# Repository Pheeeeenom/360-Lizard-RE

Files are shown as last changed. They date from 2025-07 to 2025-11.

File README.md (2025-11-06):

<div align="center">
  Lizard Logo
</div>

<h1 align="center">The Ultimate Flashing Tool</h1>

<p align="center">
  A "modern" clone to the 360 Lizard. 
</p>

# Why bother cloning this?

Mostly for preservations sake, but it really annoyed me having to deal with Windows 10/11 and driver issues, old LTU pcb's getting stuck on "writing .", JungleFlasher using very suspicious remote execution dll's (I'll be going into the software side later in the docs), the clutter of having to having cables all over the place/pc needing to be open to get access to a SATA plug. List goes on.

# Clone features

* Modernize with USB-C
* Replace the old 27 pin out of production 0.96 SPI 1306 screen with a 30 pin equivalent.
* Removeable screen so it's repairable with little effort

# Original features

* Hardware Flasher with Unlock, Read, Write, Erase, Key Retrieval
* Support all Xbox 360 Drives, Samsung, Hitachi, Benq, Liteon, and Slim Liteon. (yes it also unlock and read keys on the latest 0225)
* Built in support for many PC DVD Sata Drives too
* Support Onboard AES 128 Key Verification
* Several Modes of Operation: Use it with your PC or as stand alone
* Micro SD Card Slot for file storage
* Friendly Navigation Menu with simplified button count
* Multilingual Menu
* Free PC companion Software

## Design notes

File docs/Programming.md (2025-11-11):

# Programming / Bring up 
There's 3 total steps needed to be taken to prepare a blank board. Ideally in this order:
* Program the FTDI [.xml](https://raw.githubusercontent.com/Pheeeeenom/360-Lizard-RE/refs/heads/main/sw/FTDI/internal%20EEPROM_PD_true.xml)
* Program the PIC18F87J11 with the [.hex](https://raw.githubusercontent.com/Pheeeeenom/360-Lizard-RE/refs/heads/main/sw/MCU/lizard_v1.34_last_official_fw.hex)
* Program the SPI chip [.bin](https://github.com/Pheeeeenom/360-Lizard-RE/raw/refs/heads/main/sw/SPI/spi_v1.34_last_official_fw.bin)

# FTDI

Use FT_Prog to apply the .xml inside sw/FTDI/.

# PIC18F87J11

Use a [PICKIT 3](https://amazon.com/dp/B07PHPBP3Y) and use the [standalone programmer](https://ww1.microchip.com/downloads/en/DeviceDoc/PICkit_3_Programmer_1_0_Setup_A.zip)

<div align="center">
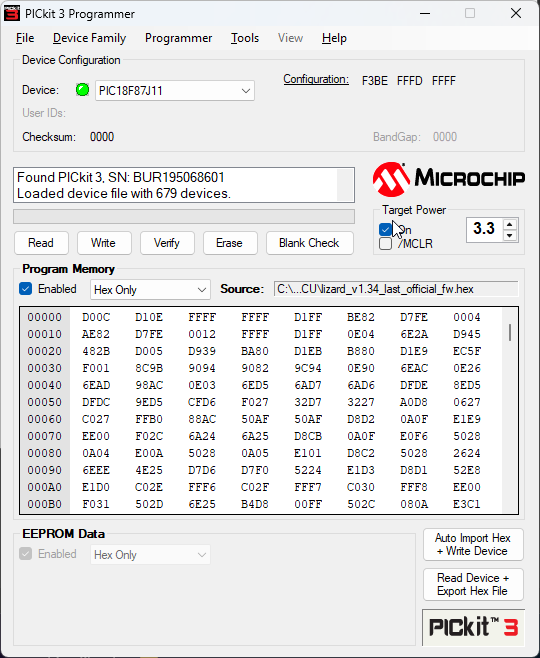
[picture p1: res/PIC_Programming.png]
PIC Settings
  
</div>

<p align="center">
Select the appropriate PIC from the device drop down then select Target Power On checkbox (be sure you do **NOT** select /MCLR). Lastly, select the .hex and click the write button.
</p>

# SPI Chip

<div align="center">
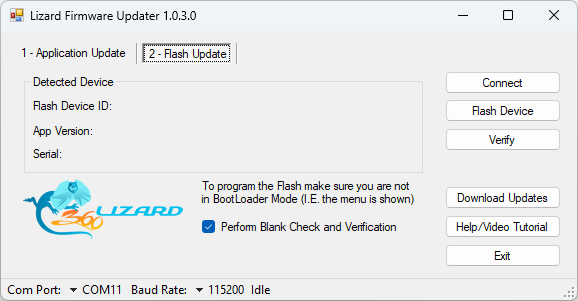
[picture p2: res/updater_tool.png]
updater settings
  
</div>

Use the [updater tool](https://github.com/Pheeeeenom/360-Lizard-RE/raw/refs/heads/main/sw/LizardFwUpdater_work_deob.exe) and click on "2 - Flash Update" then click connect and once it connects click Flash Device and select the .bin just wait.

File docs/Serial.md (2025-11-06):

# Retaining Serial Number
Get your serial number prior to doing anything by connecting your existing lizard to the PC and opening the toolbox.
# Intel HEX Checksum Calculation

## Steps
1. **Ignore** the starting colon (`:`).  
2. **Sum** all bytes in the record:
   - Byte count  
   - Address (2 bytes)  
   - Record type  
   - Data bytes  
3. **Keep only** the least significant byte of the sum (sum mod 256).  
4. **Compute the two’s complement**:
5. **Append** the checksum as the last byte.

## Example

Record without checksum: 
:1003F000B13AECEB8DCB4B3C93C79ED3398739A5

---

## Step 1: Split the record

| Field | Bytes | Description |
|---|---|---|
| Byte count | `10` | 16 data bytes |
| Address | `03 F0` | Start address 0x03F0 |
| Record type | `00` | Data record |
| Serial | `B1 3A EC EB 8D CB 4B 3C 93 C7 9E D3 39 87 39 A5` | 16 bytes |

---

## Step 2: Add all bytes (except the colon and checksum)

Let’s add step by step (hex math, keeping only 8-bit sum each time):

| Operation | Sum (Hex) |
|---|---|
| 10 + 03 | 13 |
| 13 + F0 | 103 → 03 |
| 03 + 00 | 03 |
| 03 + B1 | B4 |
| B4 + 3A | EE |
| EE + EC | 1DA → DA |
| DA + EB | 1C5 → C5 |
| C5 + 8D | 152 → 52 |
| 52 + CB | 11D → 1D |
| 1D + 4B | 68 |
| 68 + 3C | A4 |
| A4 + 93 | 137 → 37 |
| 37 + C7 | FE |
| FE + 9E | 19C → 9C |
| 9C + D3 | 16F → 6F |
| 6F + 39 | A8 |
| A8 + 87 | 12F → 2F |
| 2F + 39 | 68 |
| 68 + A5 | 10D → **0D** |

Final sum (mod 256) = **0x0D**

---

## Step 3: Take the two’s complement

0x100 - 0x0D = 0xF3

## Step 4: Append the checksum

Final Intel HEX record: :1003F000B13AECEB8DCB4B3C93C79ED3398739A5F3

## Step 5: Insert this at the appropriate line in the correct location in the hex

You can ctrl+f to find ":1003F000F1C70B8FBAF25C6CF312CC823655D6D1B2" which is the serial + checksum in the latest 1.34 hex.

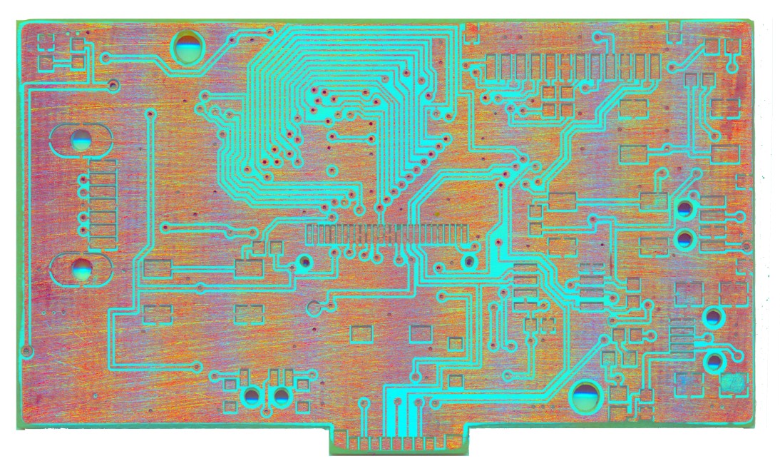
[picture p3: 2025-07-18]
board scans/top.jpg

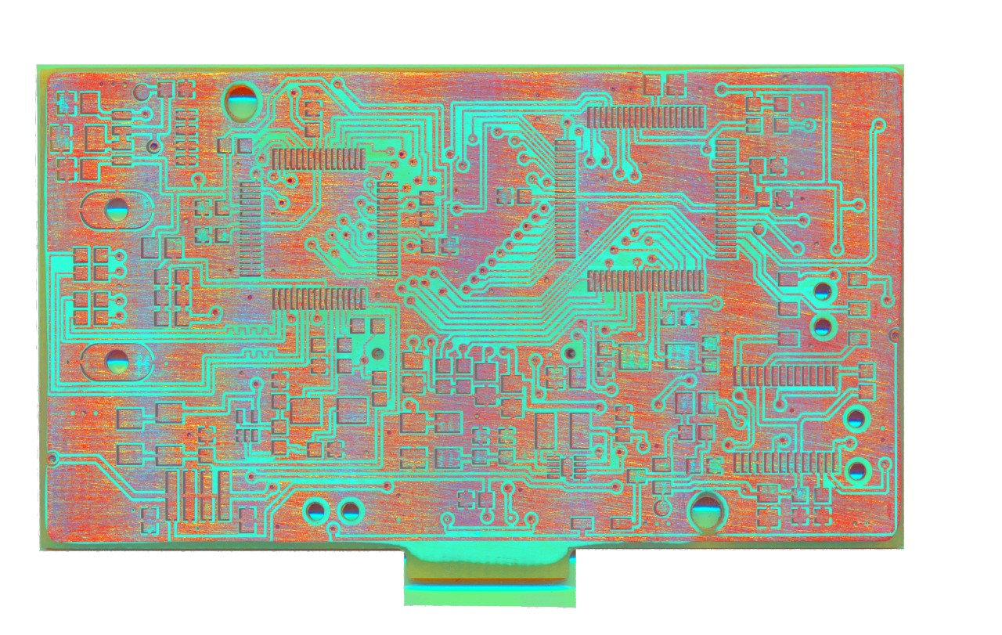
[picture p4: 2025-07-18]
board scans/bottom.jpg

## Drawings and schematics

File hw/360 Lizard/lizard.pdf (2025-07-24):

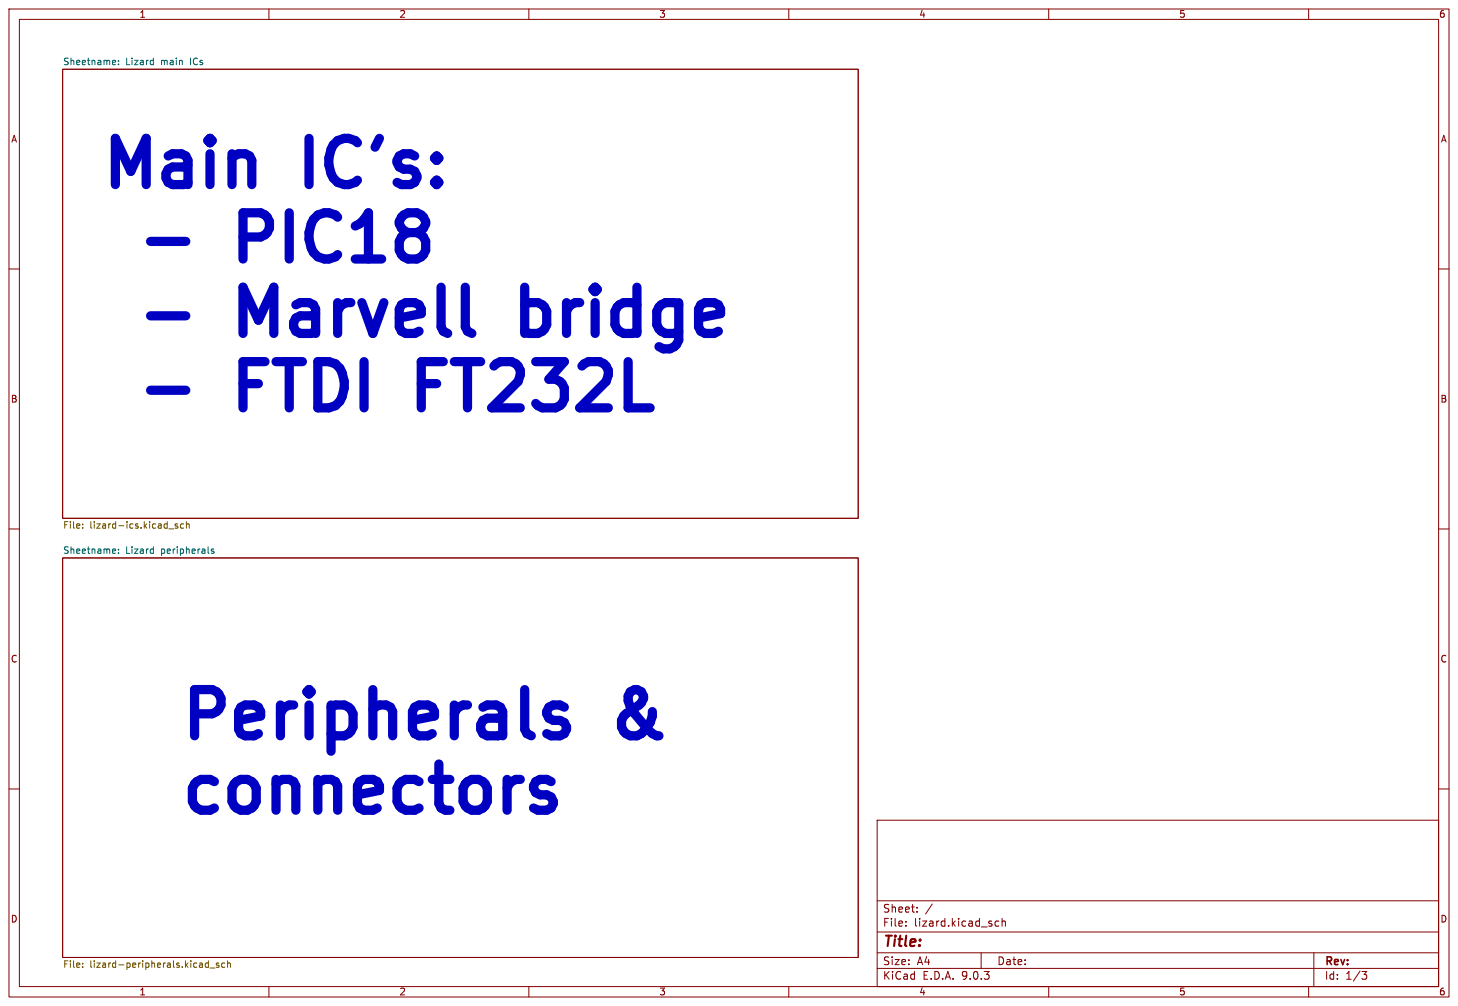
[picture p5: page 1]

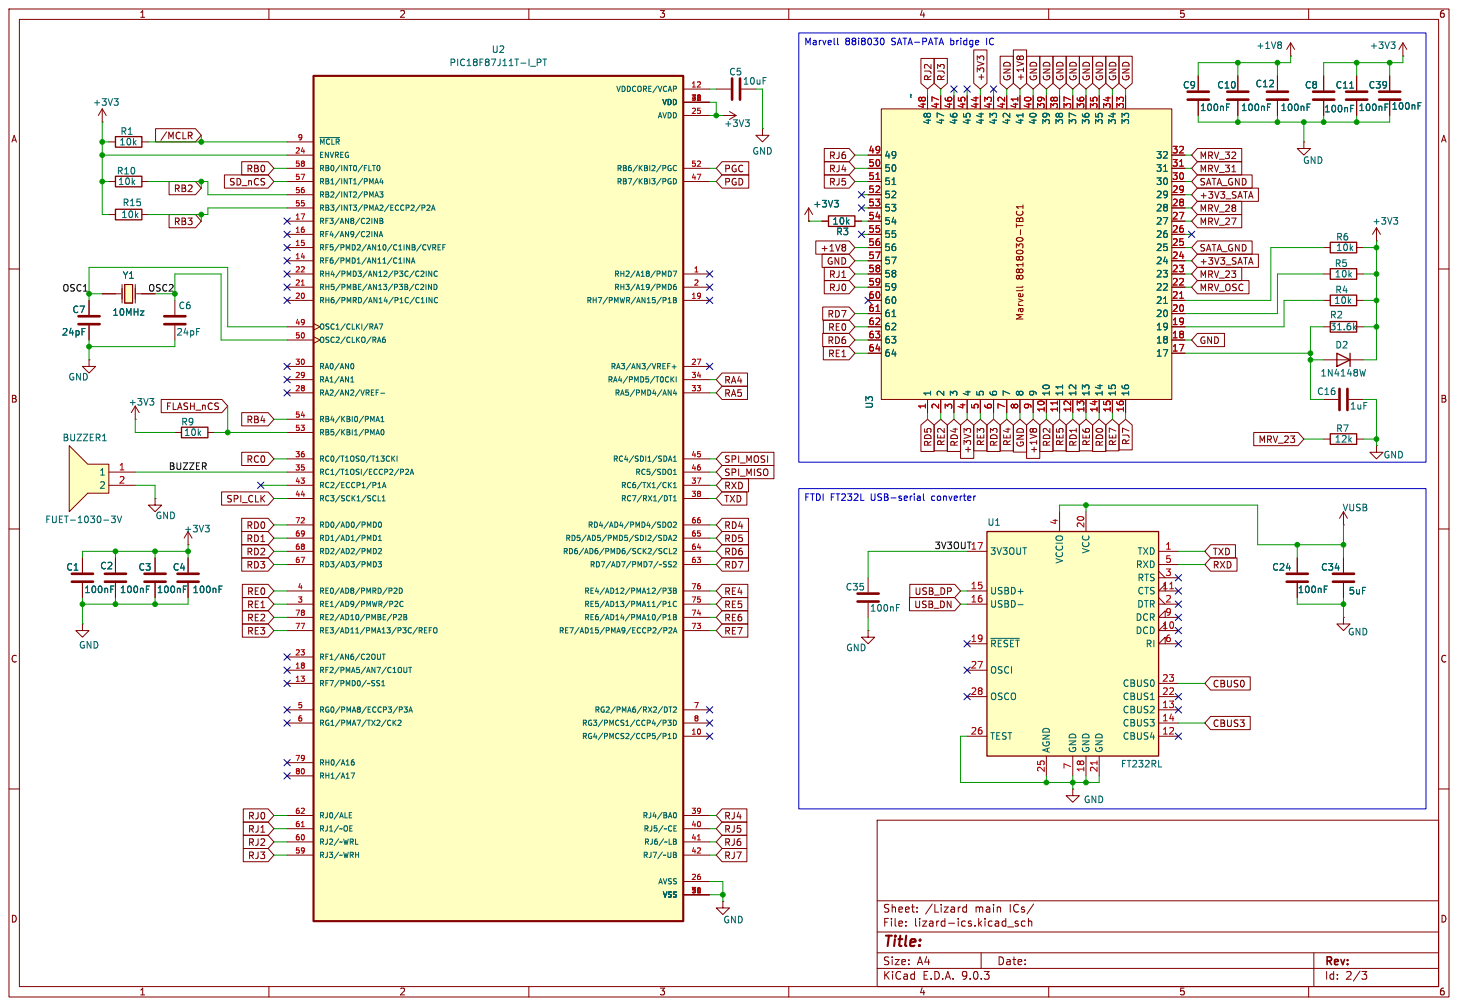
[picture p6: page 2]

7 VCC 20 GND 18 GND 21 TXD 1 RXD 5 RTS 3 CTS 11 DTR 2 DCR 9 DCD 10 RI 6 CBUS0 23 CBUS1 22 CBUS2 13 CBUS3 14 CBUS4 12 U1 FT232RL GND GND

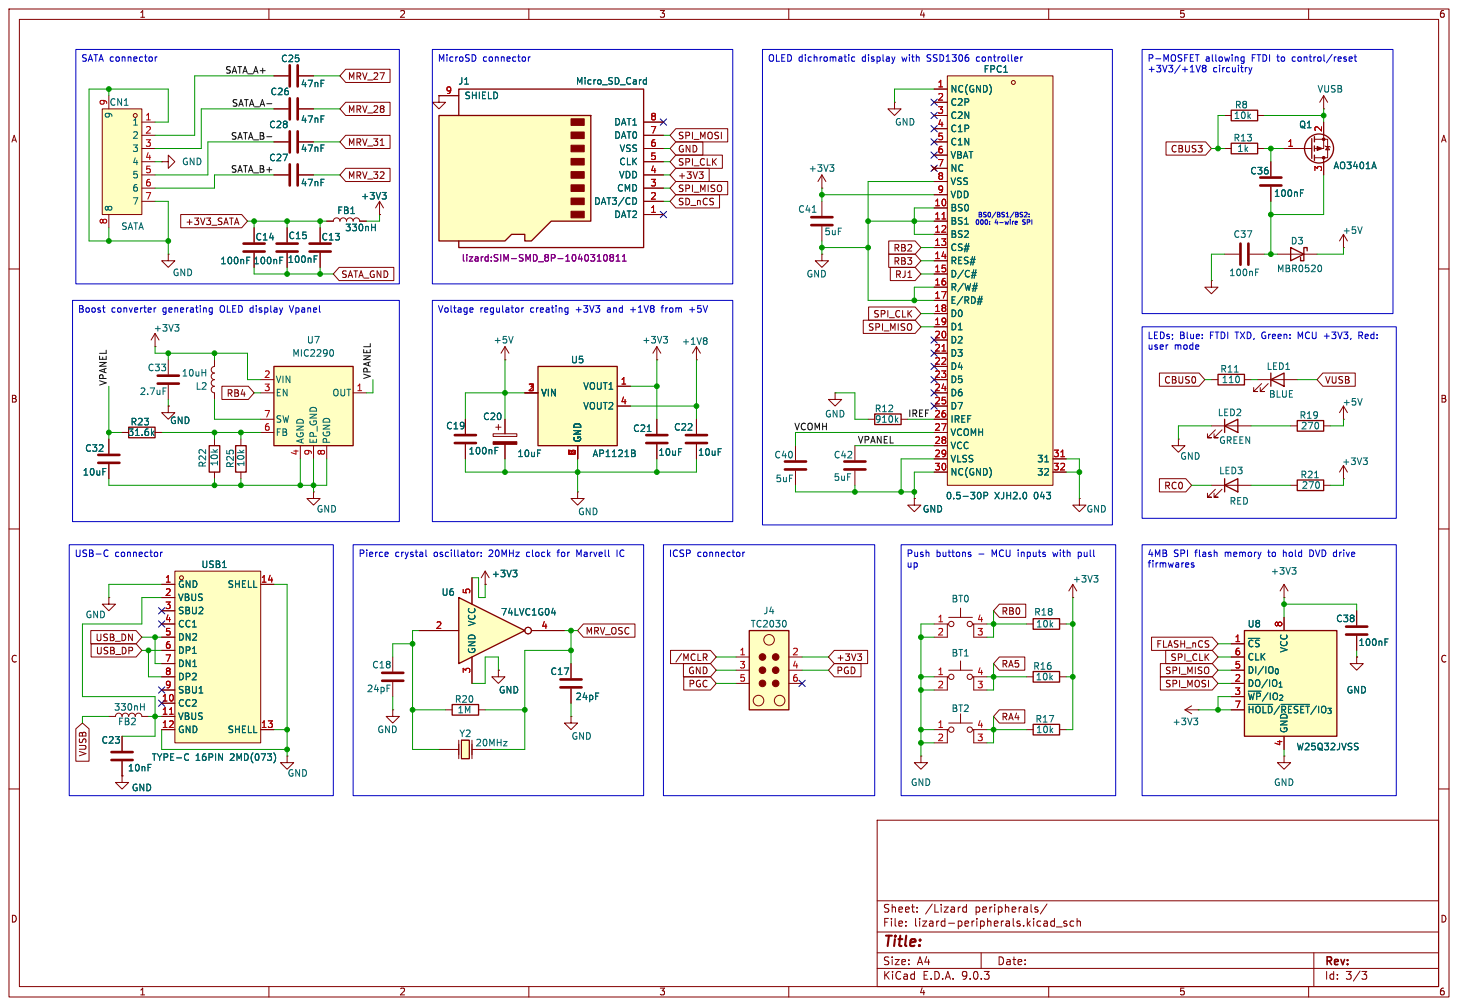
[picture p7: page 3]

4MB SPI flash memory to hold DVD drive
firmwares

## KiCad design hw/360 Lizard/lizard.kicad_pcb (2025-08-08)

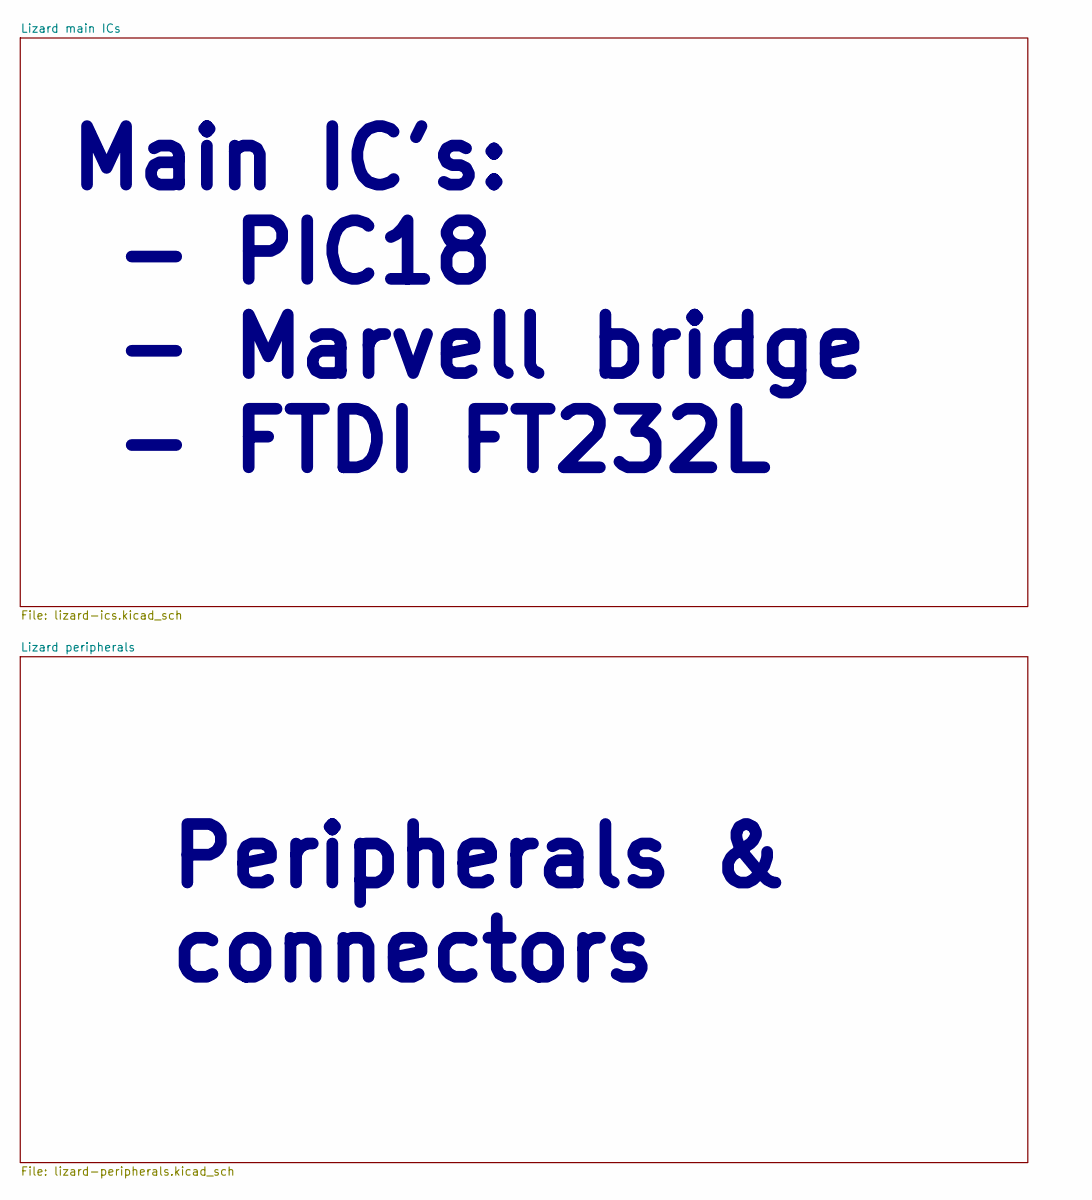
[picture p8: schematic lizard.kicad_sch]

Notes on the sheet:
Peripherals & connectors
Main IC's: - PIC18 - Marvell bridge - FTDI FT232L

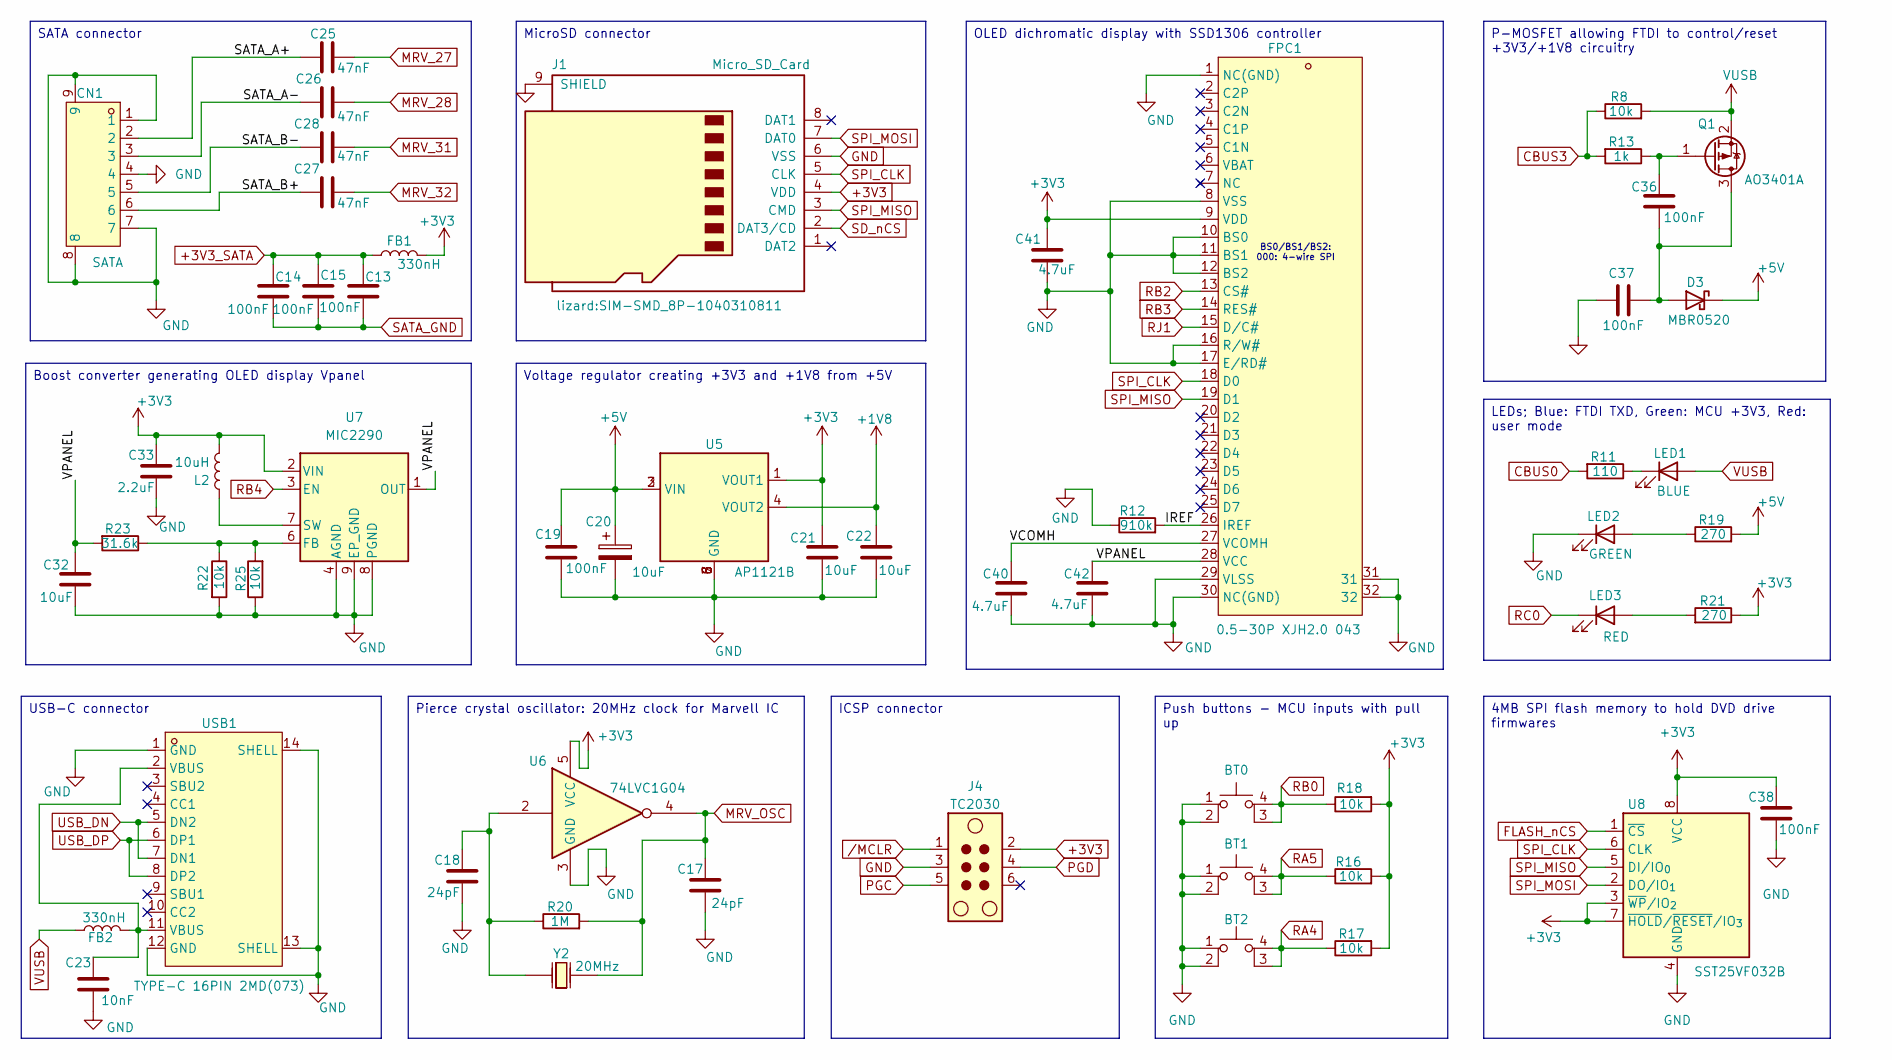
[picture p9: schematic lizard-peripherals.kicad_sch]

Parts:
BT0, BT1, BT2: SW_Push; KEY-SMD_4P-L6.0-W6.0-P4.50-LS9.0
C13, C14, C15, C19, C36, C37, C38: 100nF; C_0603_1608Metric
C17, C18: 24pF; C_0603_1608Metric
C20, C32: 10uF; C_1206_3216Metric
C21, C22: 10uF; C_0805_2012Metric
C23: 10nF; C_0603_1608Metric
C25, C26, C27, C28: 47nF; C_0603_1608Metric
C33: 2.2uF; C_0805_2012Metric
C40, C41, C42: 4.7uF; C_0805_2012Metric
CN1: SATA; CONN-SMD_SATA-401-M07S1BY-A; LCSC Part C7500835
D3: MBR0520; D_SOD-123
FB1: 330nH; L_0805_2012Metric
FB2: 330nH; L_0805_2012Metric_Pad1.15x1.40mm_HandSolder
FPC1: 0.5-30P XJH2.0 043; FPC-SMD_30P-P0.50_0.5-30P-XJH2.0-043; LCSC Part C5373440
J1: Micro_SD_Card; SIM-SMD_8P-1040310811
J4: TC2030; Tag-Connect_TC2030-IDC-NL_2x03_P1.27mm_Vertical
L2: 10uH; L_Wurth_WE-LQSH-3012
LED1: BLUE; LED_0805_2012Metric_Pad1.15x1.40mm_HandSolder
LED2: GREEN; LED_0805_2012Metric_Pad1.15x1.40mm_HandSolder
LED3: RED; LED_0805_2012Metric_Pad1.15x1.40mm_HandSolder
Q1: AO3401A; SOT-23
R8, R16, R17, R18, R22, R25: 10k; R_0603_1608Metric
R11: 110; R_0603_1608Metric
R12: 910k; R_0805_2012Metric
R13: 1k; R_0805_2012Metric
R19, R21: 270; R_0603_1608Metric
R20: 1M; R_0603_1608Metric
R23: 31.6k; R_1206_3216Metric
U5: AP1121B; TSSOP-8_3x3mm_P0.65mm
U6: 74LVC1G04; SOT-353_SC-70-5
U7: MIC2290; Micrel_MLF-8-1EP_2x2mm_P0.5mm_EP0.8x1.3mm_ThermalVias; LCSC Part # C144214
U8: SST25VF032B; SOIC-8_5.3x5.3mm_P1.27mm
USB1: TYPE-C 16PIN 2MD(073); USB-C-SMD_TYPE-C-6PIN-2MD-073; LCSC Part C2765186
Y2: 20MHz; OSC-SMD_L5.0-W3.2; LCSC Part C362485

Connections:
+1V8: C22.2, U5.4 (VOUT2); also elsewhere on the board
+3V3: C21.2, C33.1, C38.1, C41.2, FB1.1, FPC1.9 (VDD), J1.4 (VDD), J4.2, L2.2, R16.2, R17.2, R18.2, R21.1, U5.1 (VOUT1), U6.5 (VCC), U7.2 (VIN), U8.3 (~WP/IO_{2}), U8.7 (~HOLD/~RESET/IO_{3}), U8.8 (VCC); also elsewhere on the board
+3V3_SATA: C13.1, C14.1, C15.1, FB1.2; also elsewhere on the board
+5V: C19.1, C20.1, D3.1 (K), R19.2, U5.2 (VIN), U5.3 (VIN)
/Lizard peripherals/IREF: FPC1.26 (IREF), R12.2
/Lizard peripherals/SATA_A+: C25.2, CN1.2
/Lizard peripherals/SATA_A-: C26.2, CN1.3
/Lizard peripherals/SATA_B+: C27.2, CN1.6
/Lizard peripherals/SATA_B-: C28.2, CN1.5
/Lizard peripherals/VCOMH: C40.2, FPC1.27 (VCOMH)
/Lizard peripherals/VPANEL: C32.2, C42.2, FPC1.28 (VCC), R23.2, U7.1 (OUT)
CBUS0: R11.2; also elsewhere on the board
CBUS3: R8.1, R13.2; also elsewhere on the board
FLASH_nCS: U8.1 (~CS); also elsewhere on the board
GND: BT0.1, BT0.2, BT1.1, BT1.2, BT2.1, BT2.2, C17.2, C18.2, C19.2, C20.2, C21.1, C22.1, C23.1, C32.1, C33.2, C37.1, C38.2, C40.1, C41.1, C42.1, CN1.1, CN1.4, CN1.7, CN1.8, CN1.9, FPC1.1 (NC(GND)), FPC1.8 (VSS), FPC1.10 (BS0), FPC1.11 (BS1), FPC1.12 (BS2), FPC1.16 (R/W#), FPC1.17 (E/RD#), FPC1.29 (VLSS), FPC1.30 (NC(GND)), FPC1.31, FPC1.32, J1.6 (VSS), J1.9 (SHIELD), J4.3, LED2.1 (K), R12.1, R22.2, R25.1, U5.5 (GND), U5.6 (GND), U5.7 (GND), U5.8 (GND), U5.9 (GND), U6.3 (GND), U7.4 (AGND), U7.8 (PGND), U7.9 (EP_GND), U8.4 (GND), USB1.1 (GND), USB1.12 (GND), USB1.13 (SHELL), USB1.14 (SHELL); also elsewhere on the board
MRV_27: C25.1; also elsewhere on the board
MRV_28: C26.1; also elsewhere on the board
MRV_31: C28.1; also elsewhere on the board
MRV_32: C27.1; also elsewhere on the board
MRV_OSC: C17.1, R20.2, U6.4, Y2.1 (OSC1); also elsewhere on the board
unnamed: C23.2, FB2.1, USB1.2 (VBUS), USB1.11 (VBUS)
unnamed: C36.2, C37.2, D3.2 (A), Q1.3 (D)
unnamed: LED1.1 (K), R11.1
unnamed: LED2.2 (A), R19.1
unnamed: LED3.2 (A), R21.2
unnamed: C36.1, Q1.1 (G), R13.1
unnamed: R22.1, R23.1, R25.2, U7.6 (FB)
unnamed: L2.1, U7.7 (SW)
unnamed: C18.1, R20.1, U6.2, Y2.2 (OSC2)
PGC: J4.5; also elsewhere on the board
PGD: J4.4; also elsewhere on the board
RA4: BT2.3 (K), BT2.4 (A), R17.1; also elsewhere on the board
RA5: BT1.3 (K), BT1.4 (A), R16.1; also elsewhere on the board
RB0: BT0.3 (K), BT0.4 (A), R18.1; also elsewhere on the board
RB2: FPC1.13 (CS#); also elsewhere on the board
RB3: FPC1.14 (RES#); also elsewhere on the board
RB4: U7.3 (EN); also elsewhere on the board
RC0: LED3.1 (K); also elsewhere on the board
RJ1: FPC1.15 (D/C#); also elsewhere on the board
SATA_GND: C13.2, C14.2, C15.2; also elsewhere on the board
SD_nCS: J1.2 (DAT3/CD); also elsewhere on the board
SPI_CLK: FPC1.18 (D0), J1.5 (CLK), U8.6 (CLK); also elsewhere on the board
SPI_MISO: FPC1.19 (D1), J1.3 (CMD), U8.5 (DI/IO_{0}); also elsewhere on the board
SPI_MOSI: J1.7 (DAT0), U8.2 (DO/IO_{1}); also elsewhere on the board
USB_DN: USB1.5 (DN2), USB1.7 (DN1); also elsewhere on the board
USB_DP: USB1.6 (DP1), USB1.8 (DP2); also elsewhere on the board
VUSB: FB2.2, LED1.2 (A), Q1.2 (S), R8.2; also elsewhere on the board
/MCLR: J4.1; also elsewhere on the board

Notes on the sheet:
BS0/BS1/BS2: 000: 4-wire SPI
Boost converter generating OLED display Vpanel
4MB SPI flash memory to hold DVD drive firmwares
Voltage regulator creating +3V3 and +1V8 from +5V
Pierce crystal oscillator: 20MHz clock for Marvell IC
USB-C connector
SATA connector
OLED dichromatic display with SSD1306 controller
Push buttons - MCU inputs with pull up
MicroSD connector
P-MOSFET allowing FTDI to control/reset +3V3/+1V8 circuitry
LEDs; Blue: FTDI TXD, Green: MCU +3V3, Red: user mode
ICSP connector

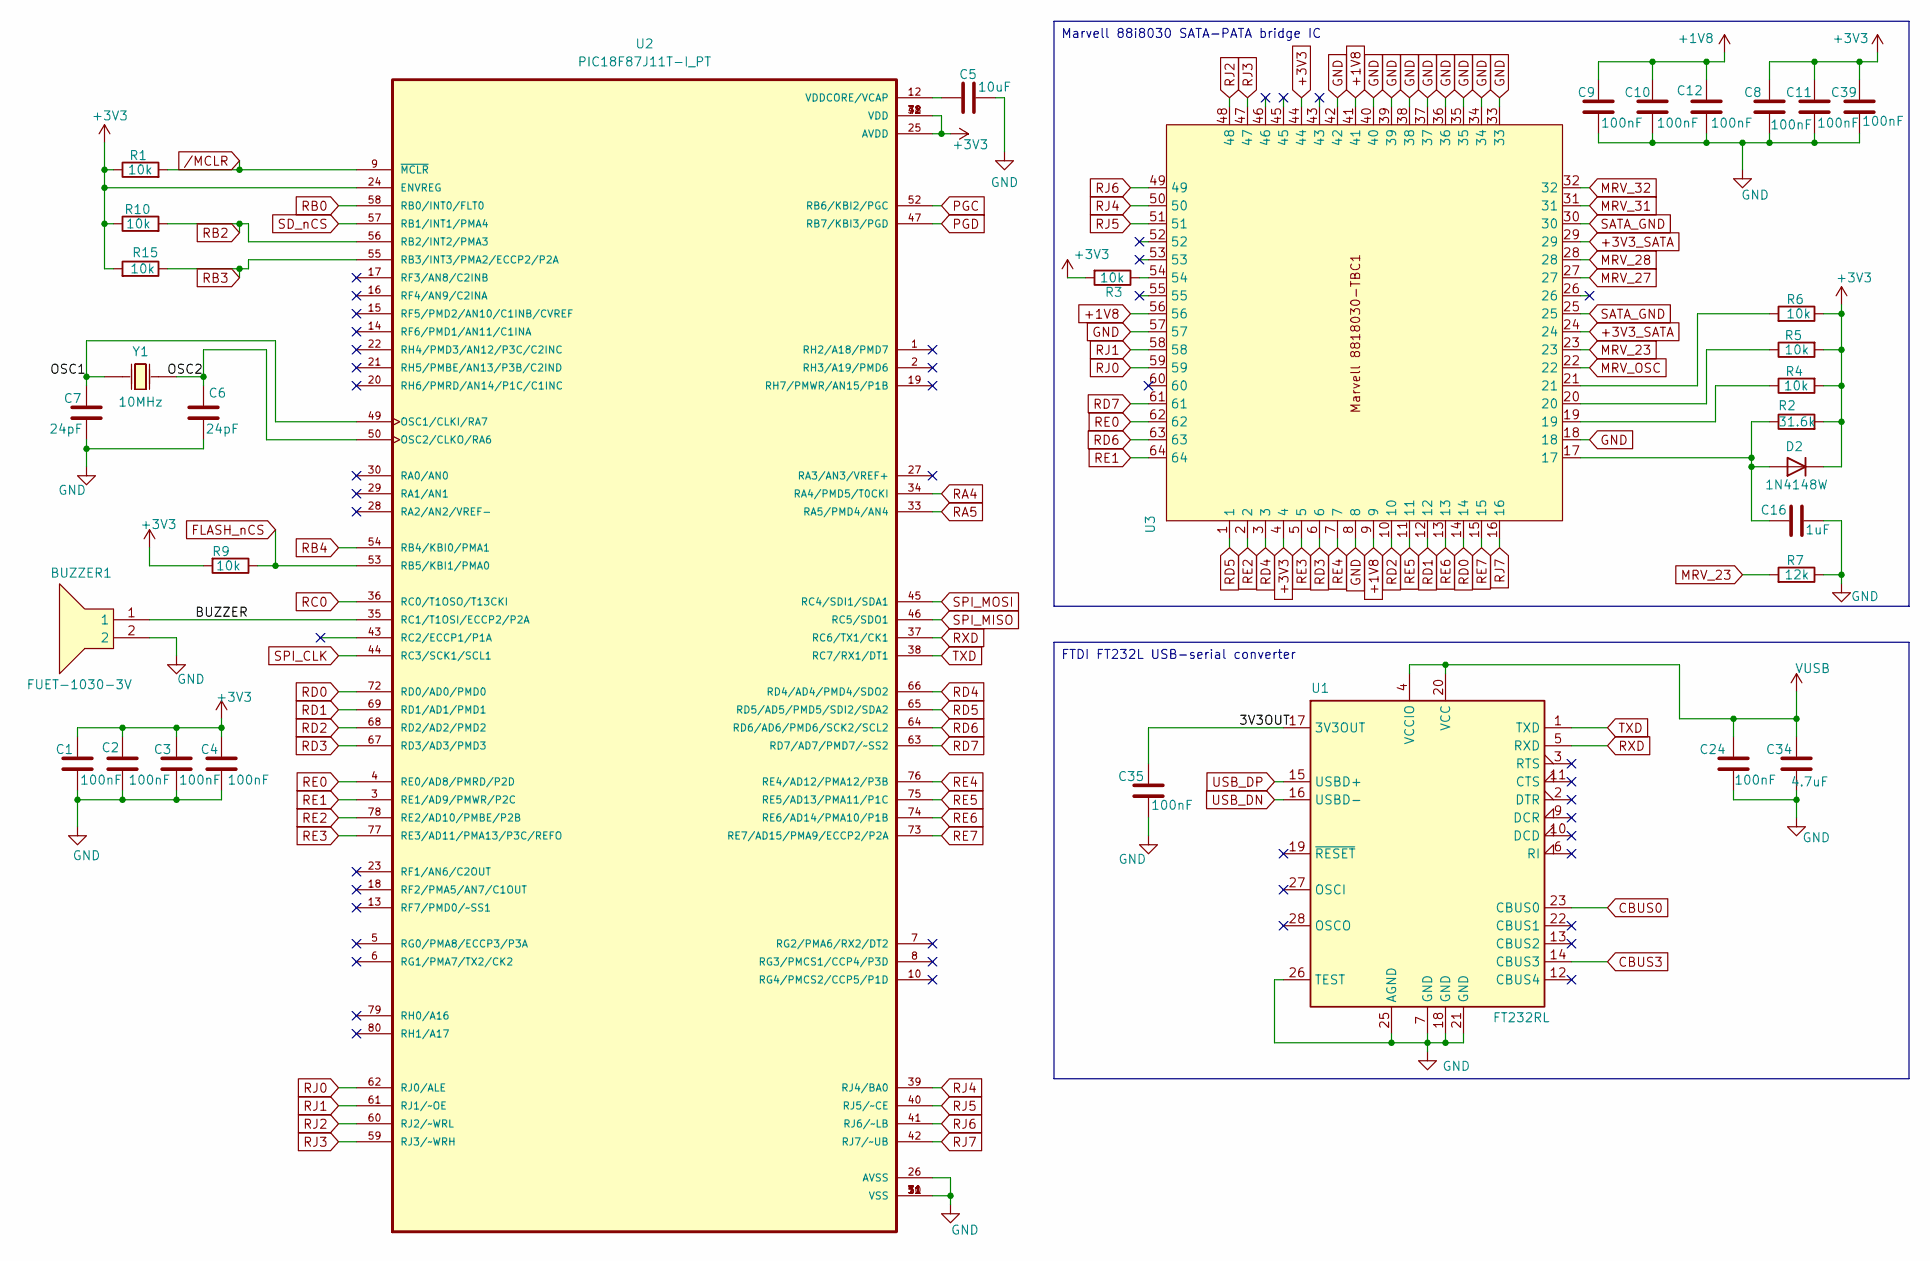
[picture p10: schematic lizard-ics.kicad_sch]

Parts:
BUZZER1: FUET-1030-3V; BUZ-SMD_FUET-1030-XXV; LCSC Part C417421
C1, C2, C3, C4, C8, C9, C10, C11, C12, C24, C35, C39: 100nF; C_0603_1608Metric
C5: 10uF; C_0805_2012Metric
C6, C7: 24pF; C_0603_1608Metric
C16: 1uF; C_0603_1608Metric
C34: 4.7uF; C_0805_2012Metric
D2: 1N4148W; D_SOD-123
R1, R3, R4, R5, R6, R9, R10, R15: 10k; R_0603_1608Metric
R2: 31.6k; R_1206_3216Metric
R7: 12k; R_0603_1608Metric
U1: FT232RL; SSOP-28_5.3x10.2mm_P0.65mm
U2: PIC18F87J11T-I_PT; QFP50P1400X1400X120-80N; DigiKey_Part_Number PIC18F87J11T-I/PTTR-ND
U3: LQFP-64_10x10mm_P0.5mm
Y1: 10MHz; OSC-SMD_L5.0-W3.2; LCSC Part C150558

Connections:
+1V8: C9.1, C10.1, C12.2, U3.9, U3.41, U3.56; also elsewhere on the board
+3V3: C1.2, C2.1, C3.1, C4.1, C8.2, C11.2, C39.2, D2.1 (K), R1.1, R2.2, R3.2, R4.2, R5.2, R6.1, R9.2, R10.1, R15.2, U2.24 (ENVREG), U2.25 (AVDD), U2.32 (VDD), U2.48 (VDD), U2.71 (VDD), U3.4, U3.44; also elsewhere on the board
+3V3_SATA: U3.24, U3.29; also elsewhere on the board
/Lizard main ICs/3V3OUT: C35.2, U1.17 (3V3OUT)
/Lizard main ICs/BUZZER: BUZZER1.1, U2.35 (RC1/T1OSI/ECCP2/P2A)
/Lizard main ICs/OSC1: C7.2, U2.49 (OSC1/CLKI/RA7), Y1.2 (OSC2)
/Lizard main ICs/OSC2: C6.2, U2.50 (OSC2/CLKO/RA6), Y1.1 (OSC1)
CBUS0: U1.23 (CBUS0); also elsewhere on the board
CBUS3: U1.14 (CBUS3); also elsewhere on the board
FLASH_nCS: R9.1, U2.53 (RB5/KBI1/PMA0); also elsewhere on the board
GND: BUZZER1.2, C1.1, C2.2, C3.2, C4.2, C5.2, C6.1, C7.1, C8.1, C9.2, C10.2, C11.1, C12.1, C16.2, C24.1, C34.1, C35.1, C39.1, R7.1, U1.7 (GND), U1.18 (GND), U1.21 (GND), U1.25 (AGND), U1.26 (TEST), U2.11 (VSS), U2.26 (AVSS), U2.31 (VSS), U2.51 (VSS), U2.70 (VSS), U3.8, U3.18, U3.33, U3.34, U3.35, U3.36, U3.37, U3.38, U3.39, U3.40, U3.42, U3.57; also elsewhere on the board
MRV_23: R7.2, U3.23
MRV_27: U3.27; also elsewhere on the board
MRV_28: U3.28; also elsewhere on the board
MRV_31: U3.31; also elsewhere on the board
MRV_32: U3.32; also elsewhere on the board
MRV_OSC: U3.22; also elsewhere on the board
unnamed: C16.1, D2.2 (A), R2.1, U3.17
unnamed: R3.1, U3.54
unnamed: R4.1, U3.19
unnamed: R5.1, U3.20
unnamed: R6.2, U3.21
unnamed: C5.1, U2.12 (VDDCORE/VCAP)
PGC: U2.52 (RB6/KBI2/PGC); also elsewhere on the board
PGD: U2.47 (RB7/KBI3/PGD); also elsewhere on the board
RA4: U2.34 (RA4/PMD5/T0CKI); also elsewhere on the board
RA5: U2.33 (RA5/PMD4/AN4); also elsewhere on the board
RB0: U2.58 (RB0/INT0/FLT0); also elsewhere on the board
RB2: R10.2, U2.56 (RB2/INT2/PMA3); also elsewhere on the board
RB3: R15.1, U2.55 (RB3/INT3/PMA2/ECCP2/P2A); also elsewhere on the board
RB4: U2.54 (RB4/KBI0/PMA1); also elsewhere on the board
RC0: U2.36 (RC0/T1OSO/T13CKI); also elsewhere on the board
RD0: U2.72 (RD0/AD0/PMD0), U3.14
RD1: U2.69 (RD1/AD1/PMD1), U3.12
RD2: U2.68 (RD2/AD2/PMD2), U3.10
RD3: U2.67 (RD3/AD3/PMD3), U3.6
RD4: U2.66 (RD4/AD4/PMD4/SDO2), U3.3
RD5: U2.65 (RD5/AD5/PMD5/SDI2/SDA2), U3.1
RD6: U2.64 (RD6/AD6/PMD6/SCK2/SCL2), U3.63
RD7: U2.63 (RD7/AD7/PMD7/~SS2), U3.61
RE0: U2.4 (RE0/AD8/PMRD/P2D), U3.62
RE1: U2.3 (RE1/AD9/PMWR/P2C), U3.64
RE2: U2.78 (RE2/AD10/PMBE/P2B), U3.2
RE3: U2.77 (RE3/AD11/PMA13/P3C/REFO), U3.5
RE4: U2.76 (RE4/AD12/PMA12/P3B), U3.7
RE5: U2.75 (RE5/AD13/PMA11/P1C), U3.11
RE6: U2.74 (RE6/AD14/PMA10/P1B), U3.13
RE7: U2.73 (RE7/AD15/PMA9/ECCP2/P2A), U3.15
RJ0: U2.62 (RJ0/ALE), U3.59
RJ1: U2.61 (RJ1/~OE), U3.58; also elsewhere on the board
RJ2: U2.60 (RJ2/~WRL), U3.48
RJ3: U2.59 (RJ3/~WRH), U3.47
RJ4: U2.39 (RJ4/BA0), U3.50
RJ5: U2.40 (RJ5/~CE), U3.51
RJ6: U2.41 (RJ6/~LB), U3.49
RJ7: U2.42 (RJ7/~UB), U3.16
RXD: U1.5 (RXD), U2.37 (RC6/TX1/CK1)
SATA_GND: U3.25, U3.30; also elsewhere on the board
SD_nCS: U2.57 (RB1/INT1/PMA4); also elsewhere on the board
SPI_CLK: U2.44 (RC3/SCK1/SCL1); also elsewhere on the board
SPI_MISO: U2.46 (RC5/SDO1); also elsewhere on the board
SPI_MOSI: U2.45 (RC4/SDI1/SDA1); also elsewhere on the board
TXD: U1.1 (TXD), U2.38 (RC7/RX1/DT1)
USB_DN: U1.16 (USBD-); also elsewhere on the board
USB_DP: U1.15 (USBD+); also elsewhere on the board
VUSB: C24.2, C34.2, U1.4 (VCCIO), U1.20 (VCC); also elsewhere on the board
/MCLR: R1.2, U2.9 (~MCLR); also elsewhere on the board

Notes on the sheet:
FTDI FT232L USB-serial converter
Marvell 88i8030 SATA-PATA bridge IC

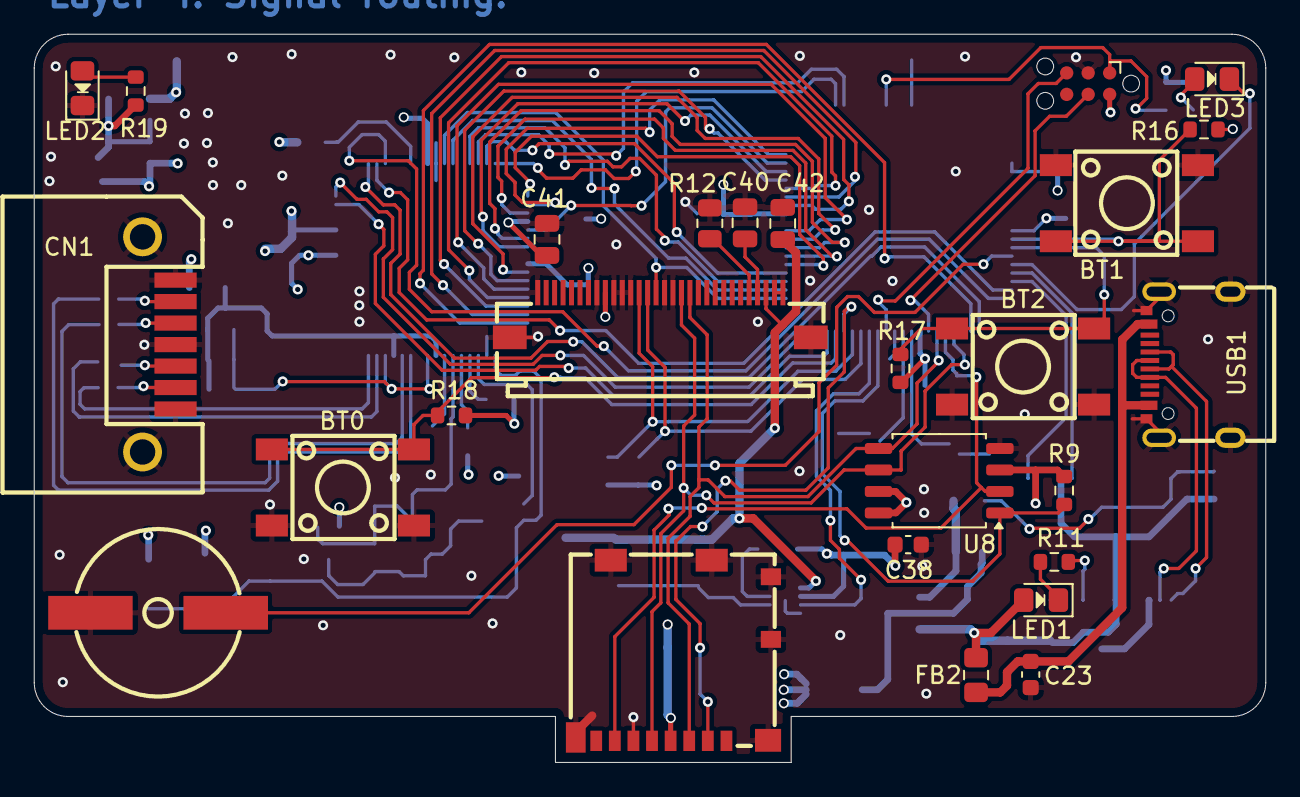
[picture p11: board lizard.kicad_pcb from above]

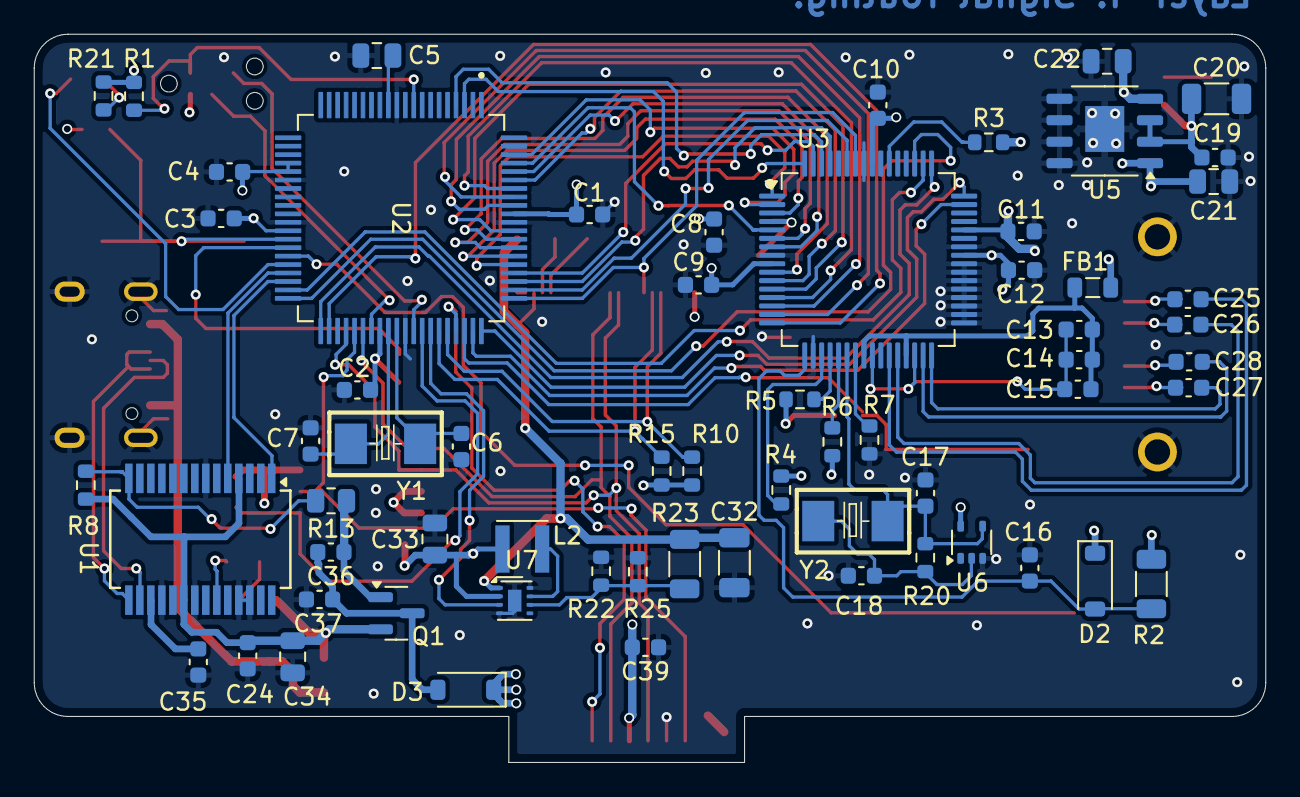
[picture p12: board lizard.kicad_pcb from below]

Board: 4 copper layers, 72.8 x 43.1 mm, 89 parts (63 on the bottom side), 84 nets.

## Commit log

2025-07-21 schematic and updater
2025-07-24 KiCad Project
    [lizard-ics.kicad_sch, lizard-peripherals.kicad_sch, lizard.kicad_pcb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]
2025-08-08 Finalized clone
    [lizard-ics.kicad_sch, lizard-peripherals.kicad_sch, lizard.kicad_pcb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]
2025-08-31 CK3 USB PD
    [BOM.xlsx, Block_Diagram.SchDoc, Buck_Regulator.SchDoc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]
2025-09-21 Updated USB PD CK3
    [BOM.xlsx, Block_Diagram.SchDoc, Buck_Regulator.SchDoc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]
2025-11-06 Board bring up instructions
2025-11-11 Add 1.33 SPI
